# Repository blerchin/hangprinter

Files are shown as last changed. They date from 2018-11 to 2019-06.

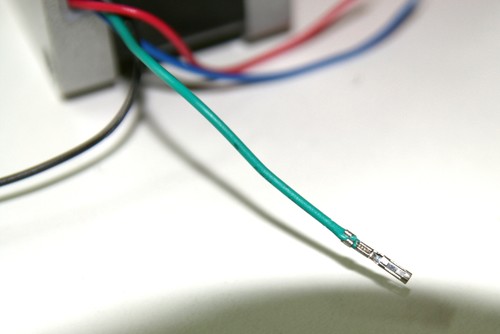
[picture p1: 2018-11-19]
doc/v3/media/Mechaduino_assembly/small_002.JPG

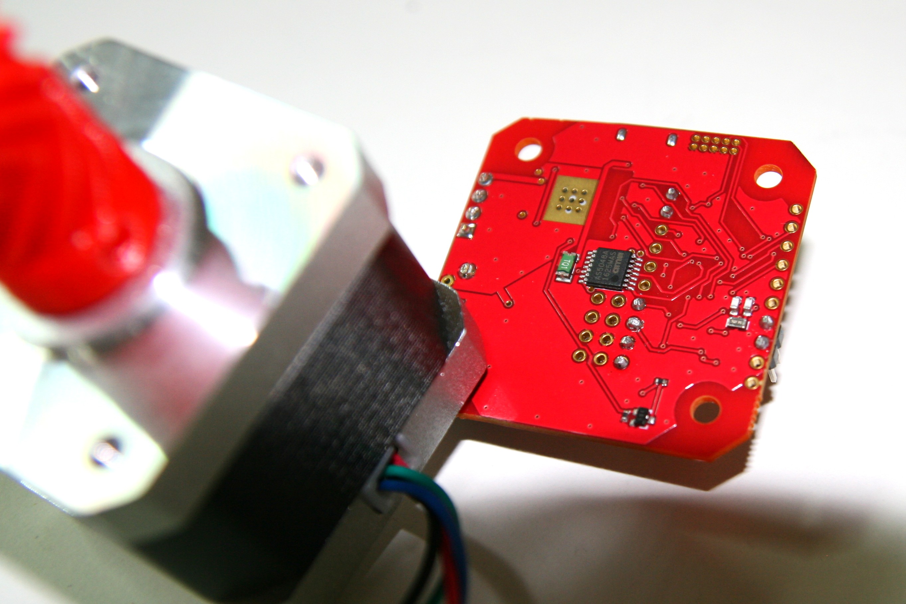
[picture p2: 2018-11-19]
doc/v3/media/Mechaduino_assembly/005.JPG

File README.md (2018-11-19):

Hangprinter Hangprinter logo
===========

This is the working branch of the Hangprinter repository.
Breaking changes may occur from time to time.
The Hangprinter repo does not yet have a stable branch.
This branch will become our (first!) stable branch when stock Marlin v2 is ready to be included as the default Hangprinter firmware.

This document and this repo are solely about technical aspects of Hangprinter version 3.
For more general information about the Hangprinter Project, refer to [hangprinter.org](https://hangprinter.org).

Bill of Materials
----------------
You can help fund future development of this project by using the affiliate links below when sourcing vitamins.
A Google Spreadsheet version for a Smart Stepper-driven setup, up to date as of Oct 10 2018, is found here: [Google docs](https://docs.google.com/spreadsheets/d/1lOPZoF1P2OSdJcijZRVrwAEVFh3LLAnf6-s6k-hlbZU/edit?usp=sharing)

Assembly Instructions
---------------------
The documentation hosted in this repo is published at [hangprinter.org/doc/v3](https://hangprinter.org/doc/v3).

Using Nema23?
----------------
Then you need different sized motor brackets, extruder holders and motor gears.
To compile those do
```
make nema23
```
This compiles the files and puts them in the `openscad_stl_nema23/` directory.
It also creates the `layout_nema23.dxf` file.
To make a 2d-printable pdf of the layout, do
```
make layout_nema23_a4.pdf
```

Using letter sized paper?
-------------------------
You can wedge that into the make-calls, like
```
make layout_letter.pdf
```
The following works if you're using nema23:
```
make layout_nema23_letter.pdf
```

The pdf creation command has been tested on a Ubuntu 14.04 system
with Cairosvg v1.0.4, sed v4.2.2, and Ghostscript v9.10.

Contributing Improvements
-------------------------
Your design improvements will help the rest of the community if you build your machine according to the files and instructions found in this repo.
The maintainers (me) are super grateful if you can structure your improvement into a pull request, and submit it to this repo.
See for example [this page](https://stackoverflow.com/questions/14680711/how-to-do-a-github-pull-request#14681796) for help with creating a pull request.

If your improvement can't be structured into a pull request, the second best option is to make an issue here on GitHub, or to contact us via the
[RepRap forum](https://reprap.org/forum/list.php?423).

Supporting This Project With Money
----------------------------------
Monthly donations can be set up via the [Bountysource Salt Campaign](https://salt.bountysource.com/teams/hangprinter).

Merchandise can be bought here: [Mechadise Sweden](http://spreadshirt.se/shops/hangprinter-merchandise).
And here: [Mechadise US](http://spreadshirt.com/shops/hangprinter-merchandise).

Bitcoin donations are accepted on: 1BwobkC5Tb7psWkzCugtcH21ufj6Lc9mgY
... or in QR format:<br />BTC Donations QR code

Credits
-------
See [contributors](https://gitlab.com/tobben/hangprinter/graphs/Openscad_version_3) for committer stats.
Note that almost all ideas implemented by the commits have come up in conversations among fellow Reprappers.
None mentioned, none forgotten, but you know who you are.
Thanks!

This repo also contains external code from many places. Some of them:
* [Greg Frost gears](http://www.thingiverse.com/thing:3575)
* [Marlin firmware](https://github.com/MarlinFirmware/Marlin)
* [scad-utils](https://github.com/openscad/scad-utils)

Currently donating $25 or more:
* [Add:north](https://addnorth.com/)
* [Aleph Objects](https://www.alephobjects.com/)
* [Alexander Osika](https://www.bountysource.com/people/49454-alexander-osika)
* [Bondtech](http://www.bondtech.se/)
* [Brooks Talley](https://www.bountysource.com/people/62525-brooks-talley)
* [David Lang](https://www.bountysource.com/people/50149-david-lang)
* [Delloman](https://www.bountysource.com/people/56602-delloman)
* [E3D](https://e3d-online.com)
* [Jeff Moe](https://www.bountysource.com/people/48391-jeff-moe)
* [John Downey](https://www.bountysource.com/people/60458-john-downey)
* [Peter Fischer](https://www.bountysource.com/people/63437-peter-fischer)

Lists sorted alphabetically.

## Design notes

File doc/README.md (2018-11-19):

# Hangprinter Documentation
This directory contains manuals written within the Hanpgrinter Project.
The files listed here are served at [hangprinter.org/doc](https://hangprinter.org/doc).

The intention is to document electronics, software, assembly, and calibration seperately and as independently as possible.
It should be possible to read them in any order and still have meaningful results.

On April 18, 2018, only the assembly manual is done. See v3/index.xml.

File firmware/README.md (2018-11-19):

## State of Hangprinter v3 firmware as of Sep 18, 2018

### Marlin
Hangprinter support was merged into Marlin's develpopment branch on Sep 9, 2018.
In this repo you'll find a copy of that development branch.
At the time of writing this, Hangprinter support has not been included in any Marlin releases yet, so we use the dev branch for now.

### Smart Stepper
Smart Stepper is a development of the Mechaduino board, capable of advanced closed loop stepper motor control.
The Smart Stepper boards provide Hangprinter with closed loop control (no skipped steps), torque mode, and encoder readings, which enable Hangprinter's semi-automatic calibration
procedure.

### No Mechaduino?
It is recommended to use the SmartStepper firmware even if you have Mechaduino hardware.
The Mechaduino firmware contained bugs that degraded Hangprinter accuracy slightly (see [this snippet](https://gitlab.com/snippets/1752083) for details).

To compile Smart Stepper Firmware for a Mechaduino board, you uncomment
```
#define MECHADUINO_HARDWARE
```
in `boards.h`, and comment out
```
#define NEMA17_SMART_STEPPER_3_21_2017
```
in the same file.

### Smart Stepper Wiring
The Smart Stepper LCD screens can not be used on a Hangprinter, since the SDA and SCL pins are needed for communicating with the host controller (RAMPS or whatever board
you've chosen for your HP3).

The Smart Stepper boards need to be configured with their own i2c addresses.
Marlin expects motor A to have i2c address 0x0a, motor b to have address 0x0b etc.
To check which i2c address your Smart Stepper has, issue
```
i2cid
```
via the serial port.
To set the address to for example `0x0b`, issue
```
i2cid 0x0b
```

It's recommended to check out the `ctrlmode` command as well.
There are two modes that can both work well with Hangprinter.

 * `controller Simple-Position-PID(2)`
 * `controller Current-Position-PID(3)`

The latter will give more silent and efficient operation on almost all motors, but requires you to do PID tuning through the `ppid` command.

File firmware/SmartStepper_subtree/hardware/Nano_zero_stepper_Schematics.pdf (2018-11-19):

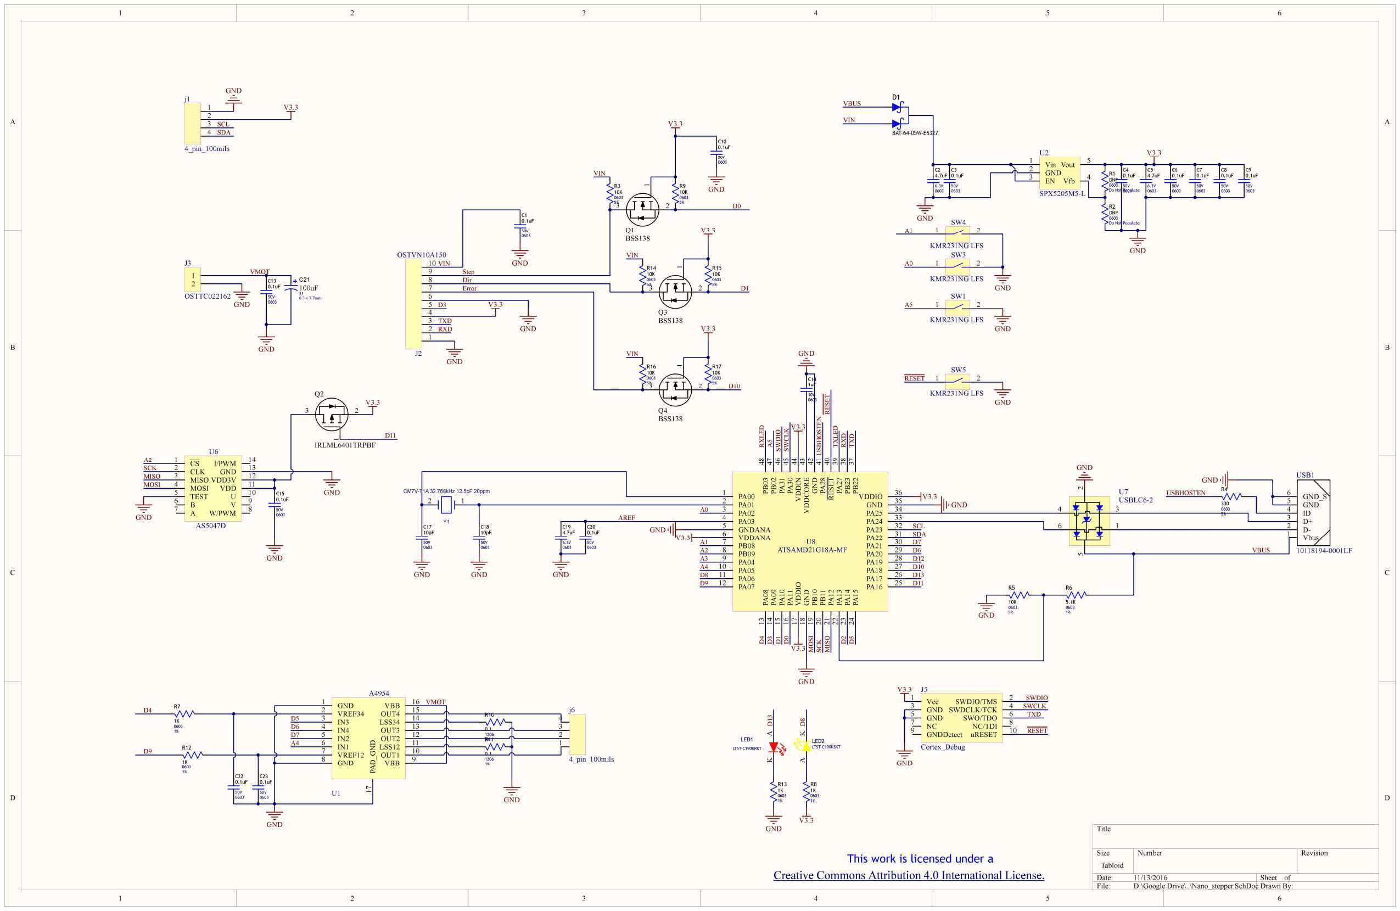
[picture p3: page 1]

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
Title

Size | Number | Revision
Tabloid
Date: | 11/13/2016 | Sheet of
File: | D:\Google Drive\..\Nano_stepper.SchDoc Drawn By:

CS 1
CLK 2
MISO 3
MOSI 4
TEST 5
B

6
A
7 | W/PWM | 8
| V | 9

U

10 VDD | 11 VDD3V | 12 GND | 13 I/PWM | 14

U6

AS5047D

PA00 1
PA01 2
PA02 3
PA03 4
GNDANA 5
VDDANA 6
PB08 7
PB09 8
PA04 9
PA05 10
PA06 11
PA07 12 | PA⁰⁸ 13 PA⁰⁹ 14 PA¹⁰ 15 PA¹¹ 16 VDDIO 17 GND 18 PB¹⁰ 19 PB¹¹ 20 PA¹² 21 PA¹³ 22 PA¹⁴ 23 PA¹⁵ 24
PA16 | 25 PA17 | 26 PA18 | 27 PA19 | 28 PA20 | 29 PA21 | 30 PA22 | 31 PA23 | 32 PA24 | 33 PA25 | 34 GND | 35 VDDIO PB²² | 36 ³⁷ PB²³ ³⁸ PA²⁷ ³⁹ RESET ⁴⁰ PA²⁸ ⁴¹ GND ⁴² VDDCORE ⁴³ VDDIN ⁴⁴ PA³⁰ ⁴⁵ PA³¹ ⁴⁶ PB⁰² ⁴⁷ PB⁰³ ⁴⁸

U8
ATSAMD21G18A-MF

2 1

Y1

CM7V-T1A 32.768kHz 12.5pF 20ppm

0603

50V

C18
10pF

0603

50V

C17
10pF
GND | GND | MOSI SCK MISO

VBUS

GND

GND

GND

GND

V3.3

V3.3

V3.3

V3.3

0603

10V

C14
1uF

GND

Vcc 1

| SWDIO/TMS | 2
GND 3
| SWDCLK/TCK | 4
GND 5
| SWO/TDO | 6
NC 7 | NC/TDI | 8
GNDDetect 9
| nRESET | 10

J5

# Cortex_Debug RESET

RESET SWDIO

SWDIO SWCLK

SWCLK

V3.3

GND A K LED2

LTST-C190KSKT

0603
1%

R13
1K
0603
1%

R8
1K

1 2

SW5

KMR231NG LFS
GND

RESET

A0
AREF

A1
A2
A3
A4
D8
D9 | D⁴ D³ D¹ D⁰ | D² D⁵

D11

D13

D10

D12

D6

D7

SDA

SCL RXD USBHOSTEN RXLED A⁵ | TXLED

A K
LED1

LTST-C190KRKT

# GNDD¹³

0603
5%

R4

330

USBHOSTEN

0603

50V

C20
0.1uF

0603

6.3V

C19
4.7uF

GND

# V3.3 D⁸

2 5

6

4

1

3

U7
USBLC6-2

GND

Vbus

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
GND_S

6

USB1

10118194-0001LF

TXD TXD

0603
5%

R5

10K
0603
1%

R6

5.1K
GND

A2

MOSI

MISO

SCK

GND

GND

Vin 1
GND 2
EN 3 | Vfb | 4
| Vout | 5

U2

SPX5205M5-L

GND

0603

50V

C4
0.1uF

0603

50V

C3
0.1uF

0603
Do Not Populate

R2
DNP

0603
Do Not Populate

R1
DNP

0603

50V

C6
0.1uF

0603

50V

C7
0.1uF

0603

50V

C8
0.1uF

0603

50V

C9
0.1uF

D1

BAT-64-05W-E6327

0603

6.3V

C5
4.7uF

VIN

VBUS

0603

6.3V

C2
4.7uF

V3.3

GND

0603

50V

C15
0.1uF

GND

GND

VMOT

GND

0603

50V

C13
0.1uF

VIN

D0

RXD | GND

GND

TXD

GND

D1

Step
Dir
Error

D3

### 6.3 x 7.7mm

100uF
35

C21

GND 1
VREF34 2
IN3 3
IN4 4
IN2 5
IN1 6
VREF12 7
GND 8 | VBB | 9
OUT1 | 10 LSS12 | 11 OUT2 | 12 OUT3 | 13 LSS34 | 14 OUT4 | 15 VBB | 16 PAD_GND
U1 | 17

A4954

D4

0603
1%

R7

1K

0603

50V

C22
0.1uF

0603

50V

C23
0.1uF

0603
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
1206
1%

R10

0.1

1206
1%

R11

0.1

VMOT

GND

1

2

3

4

j6

4_pin_100mils

D10

V3.3

D11

1 2

SW1

KMR231NG LFS
GND

1
2
3
4

j1

4_pin_100mils

A5

1 2

SW3

KMR231NG LFS
GND

A0

A4

1

3 2

Q2

IRLML6401TRPBF

1
2

J3

OSTTC022162

1 2

SW4

KMR231NG LFS

A1 ¹

3 2

Q1
BSS138

0603
5%

R3
10K

V3.3

0603
5%

R9
10K

VIN

0603

50V

C1
0.1uF | 1

3 2

Q3
BSS138

0603
5%

R14
10K

V3.3

0603
5%

R15
10K

# VIN 1

3 2

Q4
BSS138

0603
5%

R16
10K

V3.3

0603
5%

R17
10K

VIN

V3.3

0603

50V

C10
0.1uF

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
OSTVN10A150

SDA

SCL

V3.3

GND

## This work is licensed under a

Creative Commons Attribution 4.0 International License.

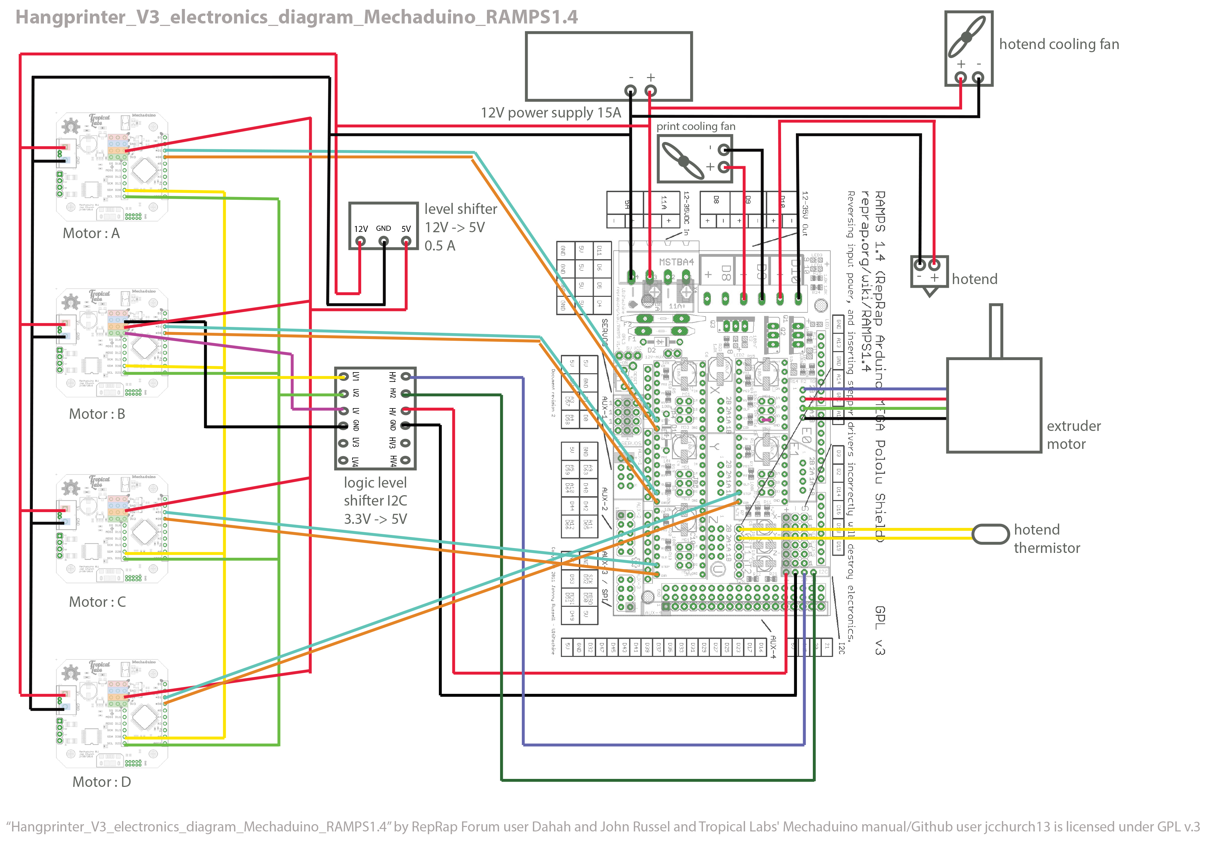
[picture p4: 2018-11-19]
doc/v3/media/Hangprinter_electronics_diagram_Mechaduino_RAMPS1.4_V2.3.jpg

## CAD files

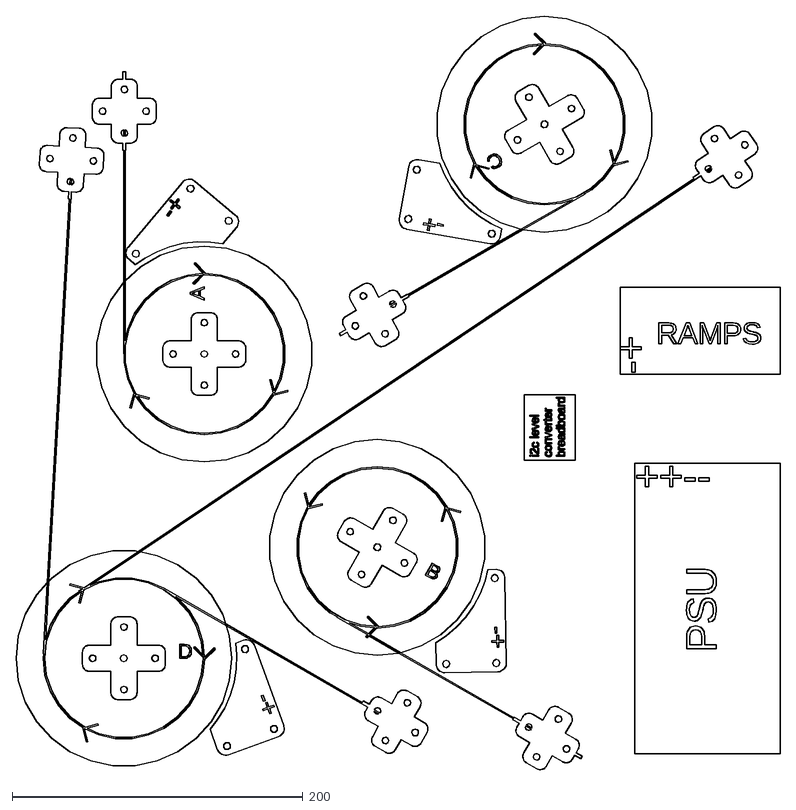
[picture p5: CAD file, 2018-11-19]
layout.dxf
525.5 x 518.1

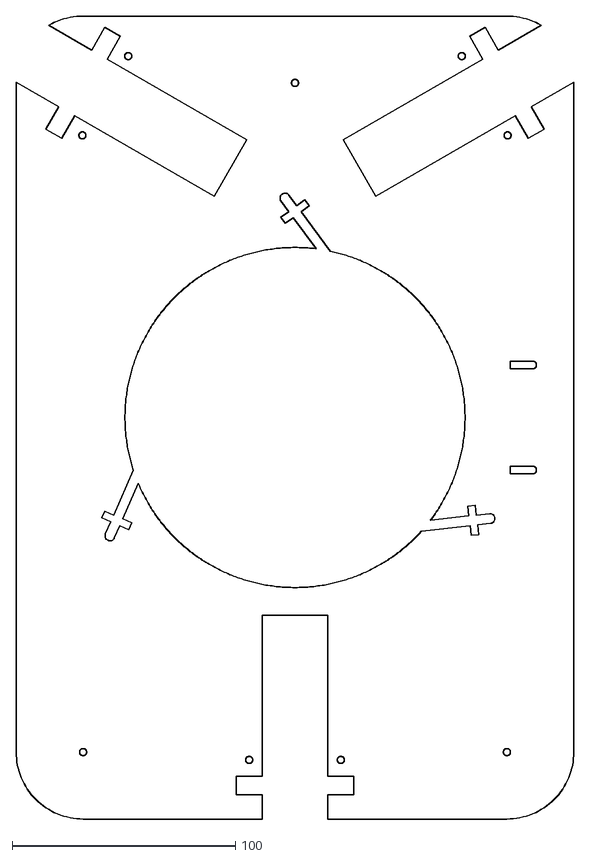
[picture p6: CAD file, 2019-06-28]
openscad_dxf/base_unit_4.dxf
250.0 x 360.0

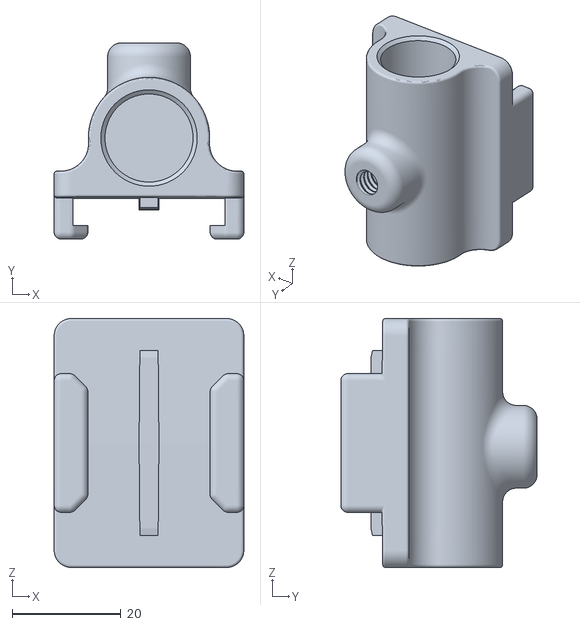
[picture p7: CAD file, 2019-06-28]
openscad_src/Light_Stand_GoPro_Mount.stl
34.9 x 36.2 x 45.8

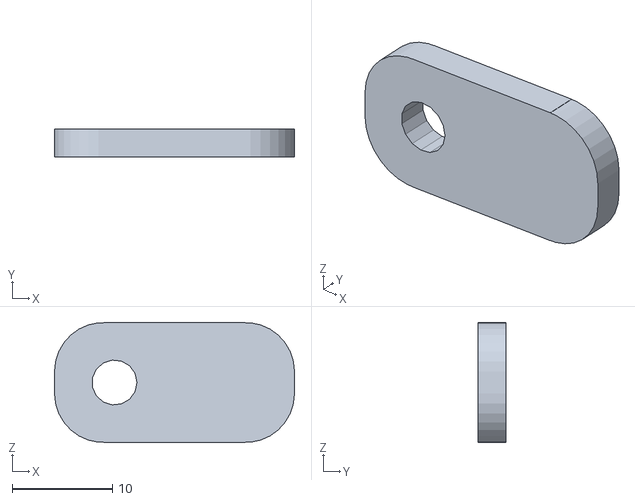
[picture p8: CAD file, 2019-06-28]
openscad_stl/axle_cover.stl
24.0 x 2.80 x 12.0

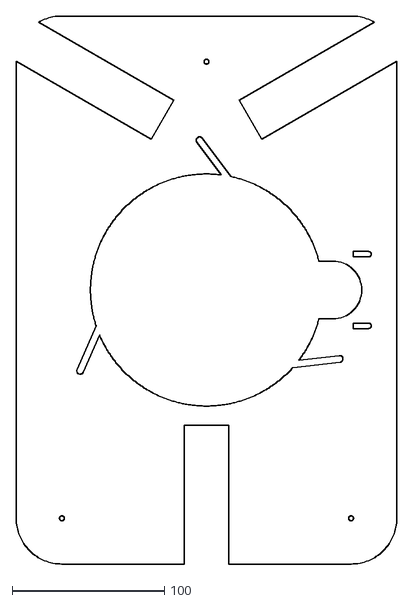
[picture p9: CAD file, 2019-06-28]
openscad_dxf/base_unit_2.dxf
250.0 x 360.0

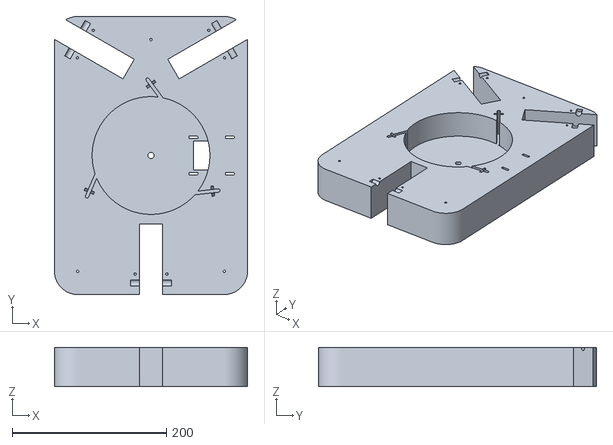
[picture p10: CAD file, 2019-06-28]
openscad_stl/base_unit.stl
250.0 x 360.0 x 50.8

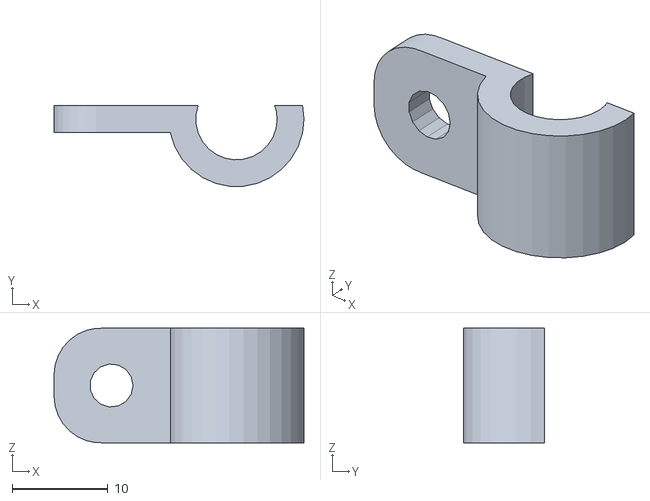
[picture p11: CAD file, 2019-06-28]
openscad_stl/axle_clamp.stl
26.1 x 8.41 x 12.0

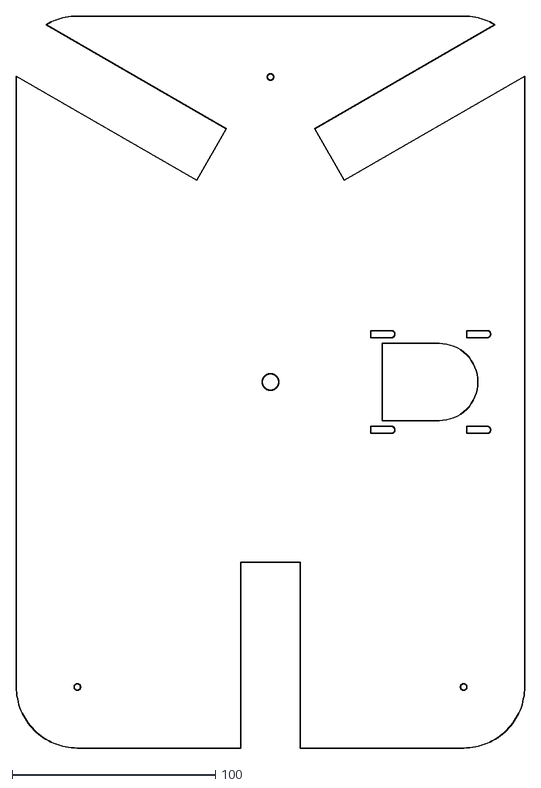
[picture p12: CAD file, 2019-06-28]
openscad_dxf/base_unit_1.dxf
250.0 x 360.0

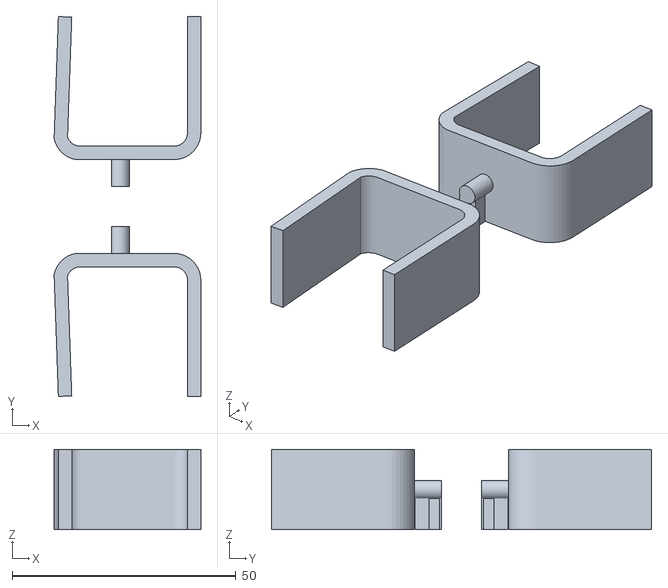
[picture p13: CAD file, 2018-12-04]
openscad_stl/lineroller_anchor_clip.stl
32.8 x 85.0 x 18.0

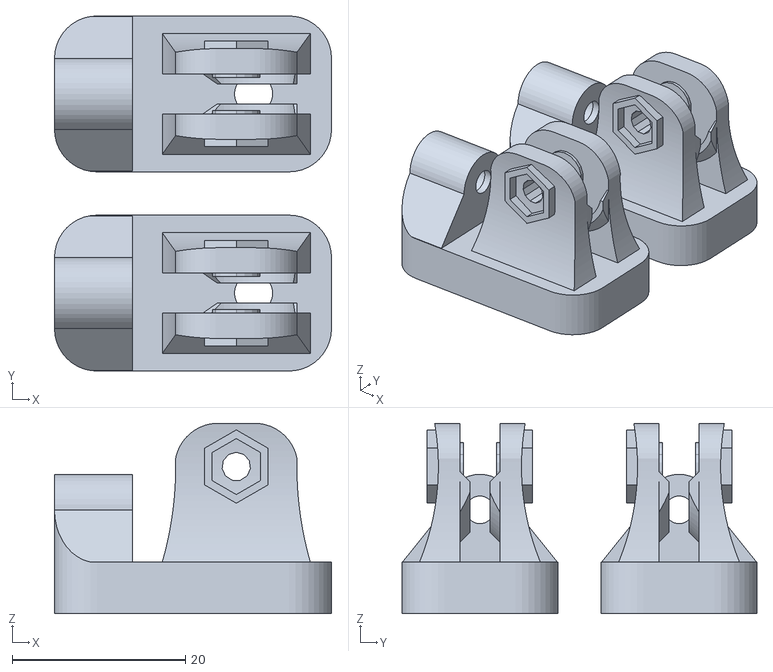
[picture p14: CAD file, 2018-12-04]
openscad_stl/lineroller_anchor_swivel.stl
32.0 x 41.0 x 22.0

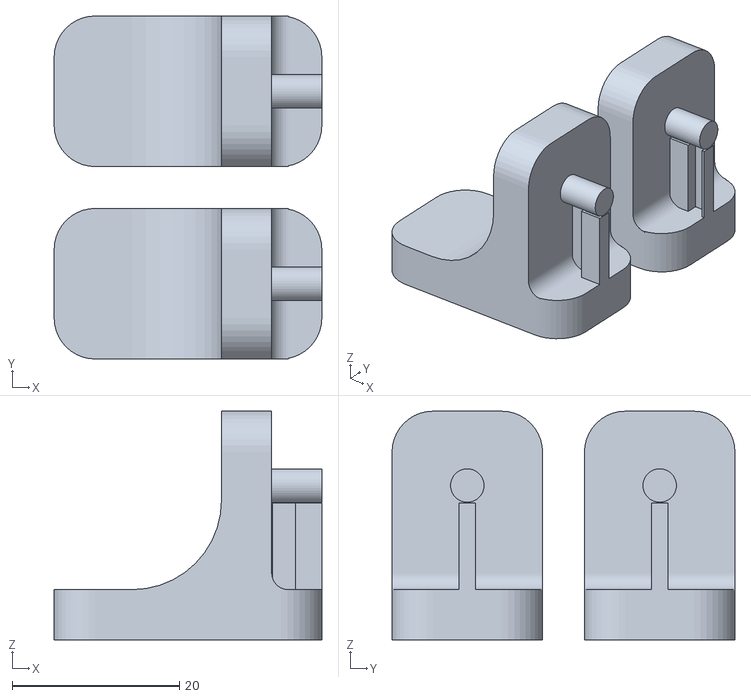
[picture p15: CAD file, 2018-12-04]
openscad_stl/lineroller_anchor_wall.stl
32.0 x 41.0 x 27.3

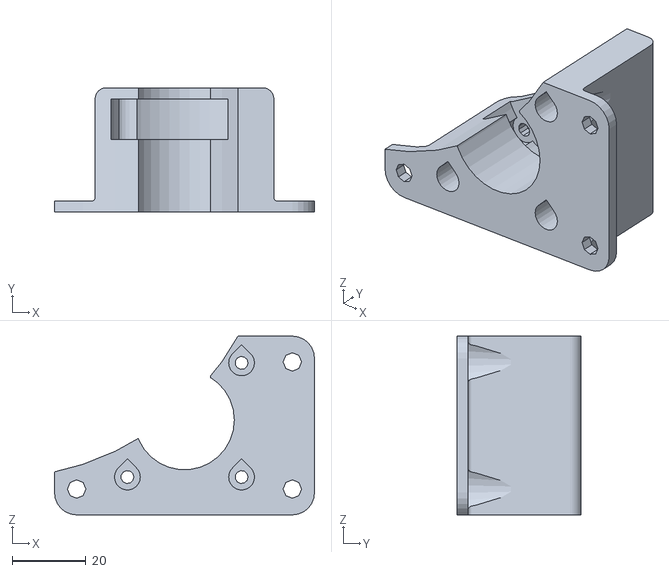
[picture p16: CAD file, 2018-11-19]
openscad_stl/motor_bracket.stl
70.4 x 33.7 x 48.4

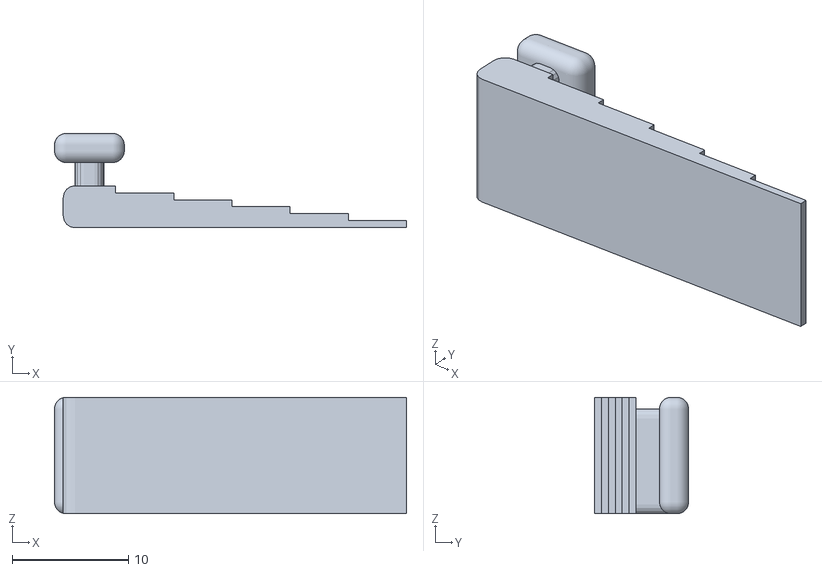
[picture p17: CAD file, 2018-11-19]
openscad_stl/beam_slider_D.stl
30.2 x 8.11 x 10.0

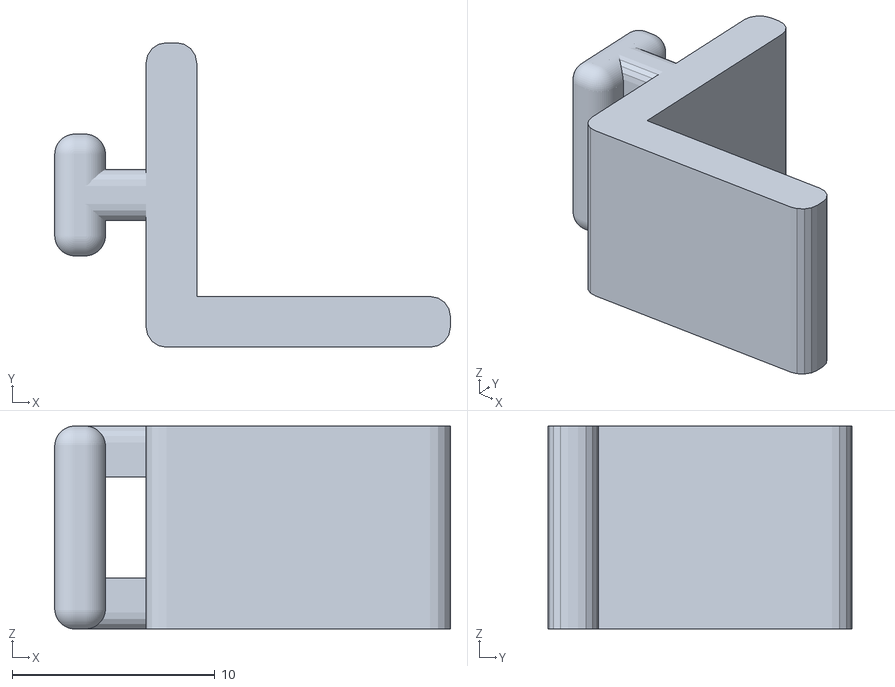
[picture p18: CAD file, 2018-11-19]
openscad_stl/beam_slider_ABC.stl
19.5 x 15.0 x 10.0

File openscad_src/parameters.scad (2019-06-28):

// Parameters shared between modules
Base_th = 2.8;
Beam_width = 15;
Wiggle = 0.25;
Fat_beam_width = Beam_width + Wiggle;
Beam_length = 400;
Wall_th = 2.5;
Min_beam_width = 12.5;
Max_beam_width = 17.5;
Zip_th = 2;
Zip_h = Zip_th + Max_beam_width - Min_beam_width;
Zip_w = 5.0;
Nema17_cube_width          = 42.43;
Nema17_screw_hole_width    = 43.74; // Opposite corner screws
Nema17_ring_diameter       = 22;
Nema17_cube_height         = 39.36;
Nema17_shaft_height        = 63.65;
Nema17_ring_height         = 2;
Nema17_shaft_radius        = 5/2;
Nema23_cube_width          = 56;
Nema23_screw_hole_width    = 66.61;
Nema23_ring_diameter       = 38;
Nema23_cube_height         = 56;
Nema23_shaft_radius        = 3.175;

b608_outer_dia = 22.2;
b608_width = 7.05;
Gap_between_sandwich_and_plate = 1.5 + Base_th; // 1.5 mm for wiggle
Motor_bracket_flerp_r = 6;
Motor_bracket_flerp = 14;
Motor_bracket_cw = Nema17_cube_width + 6;
Motor_bracket_att_ang = 50;
Mounting_screw_d = 4.5;
Mounting_screw_head_d = 14;
Spool_outer_wall_th = 4;

// Corner clamp parameters
Cc_l1 = (Fat_beam_width+2*Wall_th)*2*sqrt(3);
Cc_rad_b = 4;
Cc_action_point_from_mid = Cc_l1/sqrt(3)-2*Cc_rad_b-1.3;  // 1.3 chosen arbitrarily
Cc_plastic_length = sqrt(Cc_action_point_from_mid*Cc_action_point_from_mid
                       - (Cc_action_point_from_mid/2)*(Cc_action_point_from_mid/2));

// The distance between the two action points on the mover
Sidelength = Beam_length + 2*Cc_plastic_length;

/////// Layout parameters ////////////
Ext_sidelength = Sidelength+77;
Additional_added_plate_side_length = 10;
Yshift_top_plate = -25;

/////// Gear parameters ////////////
Circular_pitch = 262;
Motor_teeth = 10;
Gear_height = 21.4-3;
Motor_pitch                      = (Motor_teeth*Circular_pitch/360);
Motor_pitch_diametrial           = Motor_teeth/(2*Motor_pitch);
Motor_outer_radius               = Motor_pitch + 1/Motor_pitch_diametrial;
Spool_teeth = 100;
Spool_r = 55;
Spool_height = 8;
Spool_pitch                      = (Spool_teeth*Circular_pitch/360);
Spool_pitch_diametrial           = Spool_teeth/(2*Spool_pitch);
Spool_outer_radius               = Spool_pitch + 1/Spool_pitch_diametrial;
Torx_depth = 5;
Motor_bracket_depth = Gear_height+1+7+Nema17_ring_height+1+Gap_between_sandwich_and_plate;
Spool_core_flerp0 = 16+3;

/////// Lineroller parameters ////////////
b623_width  = 4;
b623_bore_r = 3/2;
b623_vgroove_big_r = 12/2;
b623_vgroove_small_r = 10/2;
Lineroller_wall_th = 2.3;
// The height that lineroller_ABC_winch will have if we include the bearing
Tower_h = Gap_between_sandwich_and_plate+Gear_height
         + Spool_height/2
         + b623_vgroove_small_r
         + b623_vgroove_big_r;
Bearing_wall = 1;
Depth_of_lineroller_tower = b623_width + 2*Wall_th; // 9
Depth_of_lineroller_base = Depth_of_lineroller_tower + 9; // 18
Ptfe_r = 2.1;
Lineroller_base_r = Depth_of_lineroller_base/2-1*(Ptfe_r+2);
Screw_h = 2;
Screw_head_h = 2;
Spool_center_bearing_wall_th = 5;

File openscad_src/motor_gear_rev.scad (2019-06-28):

include <parameters.scad>
use <util.scad>
use <gears.scad>
mirror();
motor_gear();
module motor_gear(){

  gear_height = Gear_height + 1; //Want extra millimeter to avoid first- and last layer problems.
  foot_height = 7;
  module half(){
    my_gear(Motor_teeth, gear_height/2+0.1, Circular_pitch, fac=1, slices = 2*gear_height, invert = true);
  }

  difference(){
    union(){
      translate([0,0,gear_height/2]){
        half();
        mirror([0,0,1])
          half();
      }
      translate([0,0,gear_height])
        cylinder(r=Motor_outer_radius, h=foot_height);
    }

    translate([0,0,-1])
      D_shaft(37);
    for(k=[0,120,240])
      rotate([0,0,k]){
        translate([0,Nema17_shaft_radius+0.5,gear_height])
          nutlock();
      }
    translate([0,0,gear_height+foot_height-1])
      cylinder(r1=2.5, r2=4, h=3);
    translate([0,0,gear_height+foot_height-7])
      cylinder(r=2.5, h=8);
    translate([-0.5,0,gear_height+foot_height-0.3])
      cube([1,Motor_outer_radius+1,1]);
    translate([-0.5,0,-0.7])
      cube([1,Motor_outer_radius+1,1]);

    // Cut bottom to avoid problems with elephant foot
    translate([0,0,-0.3])
    rotate_extrude(angle=360, convexity=5)
      translate([Motor_pitch-1.3,0])
      rotate([0,0,-70])
      square([4,5]);

  }
}
//  translate([0,0,-2-Nema17_cube_height])
//    Nema17();

echo("Motor gear outer radius",  Motor_outer_radius);
echo("Motor gear pitch", Motor_pitch);

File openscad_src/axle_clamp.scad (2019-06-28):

include <parameters.scad>
use <util.scad>

bit_width = 12;
axle_r=4.25;

module wing() {
  difference() {
   rotate([90,0,0])
      left_rounded_cube2([bit_width+2,bit_width,Base_th], Lineroller_base_r);
   screw();
  }


}

module screw() {
  translate([bit_width/2, 0, bit_width/2])
    rotate([90,0,0])
    translate([0,0,-1])
    cylinder(d=Mounting_screw_d, h=Base_th+2, $fs=1);
  translate([bit_width/2, 0, bit_width/2])
    rotate([90,0,0])
    translate([0,0,Base_th])
    cylinder(d2=Mounting_screw_head_d-4, d1=Mounting_screw_head_d, h=12, $fs=1);
}


difference(){
  union(){
    wing();
    translate([bit_width+axle_r+Base_th,-Base_th/2,0])
      cylinder(r=axle_r+Base_th, h=bit_width, $fs=1);
  }
  translate([0,0,-1])
    cube(bit_width+2*axle_r+2*Base_th);

  // axle...
    translate([bit_width+axle_r+Base_th,-Base_th/2,-1])
      cylinder(r=axle_r, h=bit_width+2, $fs=1);
}

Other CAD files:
logo.dxf
openscad_stl/extruder_holder.stl
openscad_stl/Mechaduino_standoff.stl
openscad_src/axle_cover.scad
gameoflife.blend
openscad_src/Mechaduino_standoff.scad
openscad_src/base_unit.scad
openscad_src/beam_slider_ABC.scad
openscad_src/beam_slider_D.scad
openscad_src/cable_clamp.scad
openscad_src/corner_clamp.scad
openscad_src/extruder_holder.scad
openscad_src/gear_util.scad
openscad_src/gears.scad
openscad_src/layout.scad
openscad_src/layout_slicer.scad
openscad_src/lineroller_ABC_winch.scad
openscad_src/lineroller_D.scad
openscad_src/lineroller_anchor.scad
openscad_src/lineroller_anchor_clip.scad
openscad_src/lineroller_anchor_swivel.scad
openscad_src/lineroller_anchor_template.scad
openscad_src/lineroller_anchor_tripod_bracket.scad
openscad_src/lineroller_anchor_wall.scad
openscad_src/lineroller_base.scad
openscad_src/motor_bracket.scad
openscad_src/motor_bracket_2d.scad
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

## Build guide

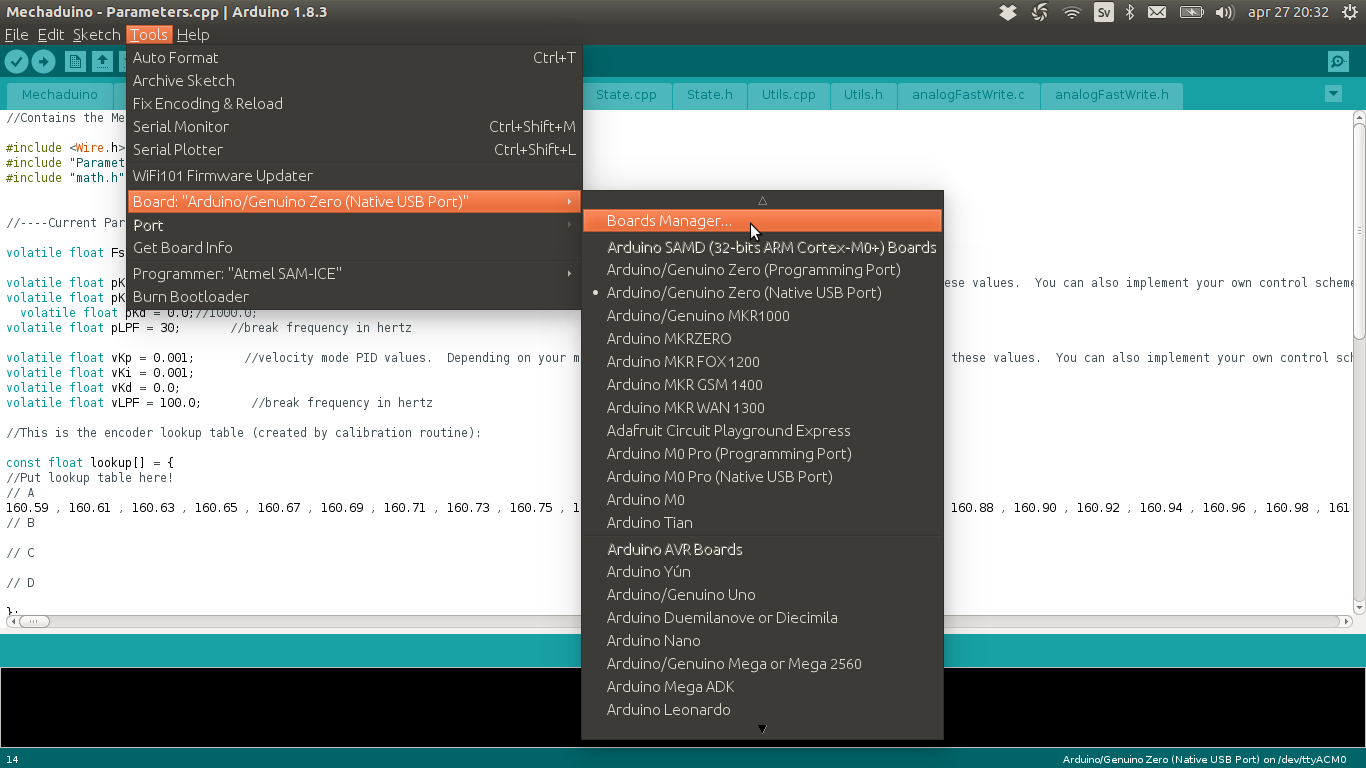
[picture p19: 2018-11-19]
doc/v3/media/Mechaduino_assembly/tools_menu2.png

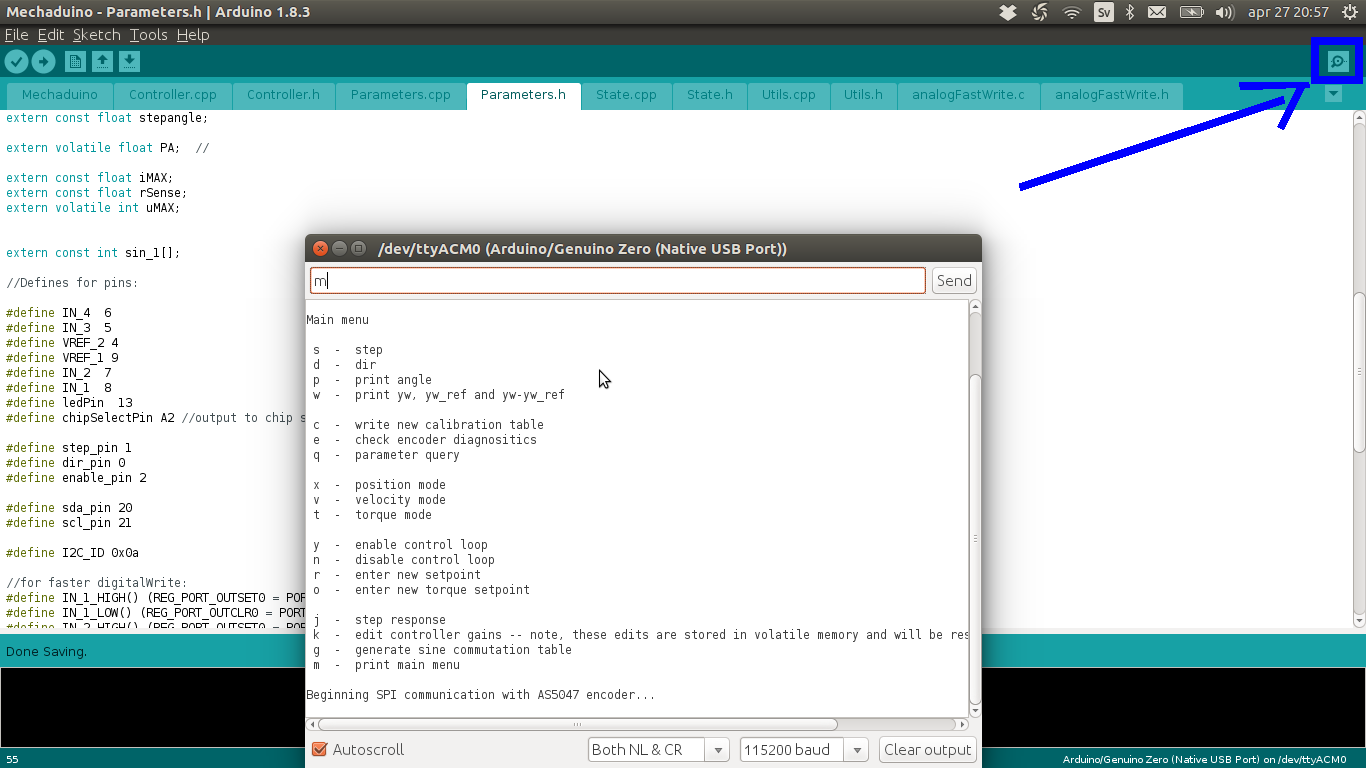
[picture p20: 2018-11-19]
doc/v3/media/Mechaduino_assembly/serial_monitor_usage_e.png

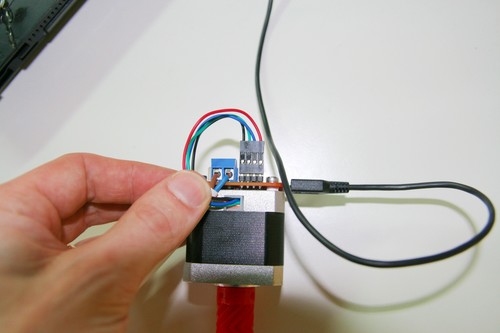
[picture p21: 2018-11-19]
doc/v3/media/Mechaduino_assembly/small_010.JPG

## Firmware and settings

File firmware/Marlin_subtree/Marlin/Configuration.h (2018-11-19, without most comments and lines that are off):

#define CONFIGURATION_H
#define CONFIGURATION_H_VERSION 010109
#define STRING_CONFIG_H_AUTHOR "(none, default config)" // Who made the changes.
#define SHOW_BOOTSCREEN
#define STRING_SPLASH_LINE1 SHORT_BUILD_VERSION // will be shown during bootup in line 1
#define STRING_SPLASH_LINE2 WEBSITE_URL         // will be shown during bootup in line 2
#define SERIAL_PORT 0
#define BAUDRATE 250000
  #define MOTHERBOARD BOARD_RAMPS_14_EFB
#define CUSTOM_MACHINE_NAME "Hangprinter"
#define EXTRUDERS 1
#define DEFAULT_NOMINAL_FILAMENT_DIA 3
#define POWER_SUPPLY 1
#define TEMP_SENSOR_0 5 // Setting gotten from wiki.e3d-online.net instructions for V6 hot end
#define TEMP_SENSOR_1 0
#define TEMP_SENSOR_2 0
#define TEMP_SENSOR_3 0
#define TEMP_SENSOR_4 0
#define TEMP_SENSOR_BED 0
#define TEMP_SENSOR_CHAMBER 0
#define DUMMY_THERMISTOR_998_VALUE 25
#define DUMMY_THERMISTOR_999_VALUE 100
#define MAX_REDUNDANT_TEMP_SENSOR_DIFF 10
#define TEMP_RESIDENCY_TIME 10  // (seconds)
#define TEMP_HYSTERESIS 3       // (degC) range of +/- temperatures considered "close" to the target one
#define TEMP_WINDOW     1       // (degC) Window around target to start the residency timer x degC early.
#define TEMP_BED_RESIDENCY_TIME 10  // (seconds)
#define TEMP_BED_HYSTERESIS 3       // (degC) range of +/- temperatures considered "close" to the target one
#define TEMP_BED_WINDOW     1       // (degC) Window around target to start the residency timer x degC early.
#define HEATER_0_MINTEMP 5
#define HEATER_1_MINTEMP 5
#define HEATER_2_MINTEMP 5
#define HEATER_3_MINTEMP 5
#define HEATER_4_MINTEMP 5
#define BED_MINTEMP 5
#define HEATER_0_MAXTEMP 275
#define HEATER_1_MAXTEMP 275
#define HEATER_2_MAXTEMP 275
#define HEATER_3_MAXTEMP 275
#define HEATER_4_MAXTEMP 275
#define BED_MAXTEMP 150
#define PIDTEMP
#define BANG_MAX 255     // Limits current to nozzle while in bang-bang mode; 255=full current
#define PID_MAX BANG_MAX // Limits current to nozzle while PID is active (see PID_FUNCTIONAL_RANGE below); 255=full current
#define PID_K1 0.95      // Smoothing factor within any PID loop
  #define PID_FUNCTIONAL_RANGE 10 // If the temperature difference between the target temperature and the actual temperature
  #define  DEFAULT_Kp 31.39
  #define  DEFAULT_Ki 2.80
  #define  DEFAULT_Kd 88.06
#define MAX_BED_POWER 255 // limits duty cycle to bed; 255=full current
#define PREVENT_COLD_EXTRUSION
#define EXTRUDE_MINTEMP 170
#define PREVENT_LENGTHY_EXTRUDE
#define EXTRUDE_MAXLENGTH 200
#define THERMAL_PROTECTION_HOTENDS // Enable thermal protection for all extruders
#define THERMAL_PROTECTION_BED     // Enable thermal protection for the heated bed
#define DEFAULT_E_AXIS_STEPS_PER_UNIT 410.0 // 410.0 set quite at random
#define HANGPRINTER
  #define KINEMATIC_SEGMENTS_PER_SECOND 40
  #define HANGPRINTER_PRINTABLE_RADIUS 1500.0
  #define ANCHOR_A_Y  -935
  #define ANCHOR_A_Z  -136
  #define ANCHOR_B_X   727
  #define ANCHOR_B_Y   458
  #define ANCHOR_B_Z  -136
  #define ANCHOR_C_X  -727
  #define ANCHOR_C_Y   458
  #define ANCHOR_C_Z  -136
  #define ANCHOR_D_Z  3565
  #define CONVENTIONAL_GEOMETRY
  #define LINE_BUILDUP_COMPENSATION_FEATURE
    #define MECHANICAL_ADVANTAGE { 1, 1, 1, 1 }
    #define ACTION_POINTS { 2, 2, 2, 3 }
    #define SPOOL_BUILDUP_FACTOR 0.0078
    #define MOUNTED_LINE { 7500.0, 7500.0, 7500.0, 5000.0 }
    #define SPOOL_RADII { 54.8, 54.8, 54.8, 54.8 }
    #define MOTOR_GEAR_TEETH { 10, 10, 10, 10 }
    #define SPOOL_GEAR_TEETH { 100, 100, 100, 100 }
#define UNREGISTERED_MOVE_SUPPORT
#define MECHADUINO_I2C_COMMANDS
#define ENDSTOPPULLUPS
#define X_MIN_ENDSTOP_INVERTING true  // set to true to invert the logic of the endstop.
#define Y_MIN_ENDSTOP_INVERTING true  // set to true to invert the logic of the endstop.
#define Z_MIN_ENDSTOP_INVERTING true  // set to true to invert the logic of the endstop.
#define X_MAX_ENDSTOP_INVERTING true  // set to true to invert the logic of the endstop.
#define Y_MAX_ENDSTOP_INVERTING true  // set to true to invert the logic of the endstop.
#define Z_MAX_ENDSTOP_INVERTING true  // set to true to invert the logic of the endstop.
#define Z_MIN_PROBE_ENDSTOP_INVERTING true  // set to true to invert the logic of the probe.
#define DEFAULT_AXIS_STEPS_PER_UNIT   { 92.599, 92.599, 92.599, 92.599, DEFAULT_E_AXIS_STEPS_PER_UNIT }
#define DEFAULT_MAX_FEEDRATE          { 500, 500, 500, 300, 25 }
#define DEFAULT_MAX_ACCELERATION      { 1000, 1000, 1000, 1000, 10000 }
#define DEFAULT_ACCELERATION          600    // X, Y, Z and E acceleration for printing moves
#define DEFAULT_RETRACT_ACCELERATION  3000    // E acceleration for retracts
#define DEFAULT_TRAVEL_ACCELERATION   900    // X, Y, Z acceleration for travel (non printing) moves
#define DEFAULT_AJERK                 13.0
#define DEFAULT_BJERK                 13.0
#define DEFAULT_CJERK                 13.0
#define DEFAULT_DJERK                 13.0
#define DEFAULT_EJERK                  5.0
#define Z_MIN_PROBE_USES_Z_MIN_ENDSTOP_PIN
#define X_PROBE_OFFSET_FROM_EXTRUDER 0     // X offset: -left  +right  [of the nozzle]
#define Y_PROBE_OFFSET_FROM_EXTRUDER -10   // Y offset: -front +behind [the nozzle]
#define Z_PROBE_OFFSET_FROM_EXTRUDER -3.5  // Z offset: -below +above  [the nozzle]
#define MIN_PROBE_EDGE 10
#define XY_PROBE_SPEED 4000
#define Z_PROBE_SPEED_FAST DUMMY_HOMING_FEEDRATE
#define Z_PROBE_SPEED_SLOW (Z_PROBE_SPEED_FAST / 2)
#define Z_CLEARANCE_DEPLOY_PROBE   15 // Z Clearance for Deploy/Stow
#define Z_CLEARANCE_BETWEEN_PROBES  5 // Z Clearance between probe points
#define Z_CLEARANCE_MULTI_PROBE     5 // Z Clearance between multiple probes
#define Z_PROBE_LOW_POINT          -2 // Farthest distance below the trigger-point to go before stopping
#define Z_PROBE_OFFSET_RANGE_MIN -20
#define Z_PROBE_OFFSET_RANGE_MAX 20
#define X_ENABLE_ON 0
#define Y_ENABLE_ON 0
#define Z_ENABLE_ON 0
#define E_ENABLE_ON 0 // For all extruders
#define DISABLE_X false
#define DISABLE_Y false
#define DISABLE_Z false
#define DISABLE_E false // For all extruders
#define DISABLE_INACTIVE_EXTRUDER false // Keep only the active extruder enabled.
#define INVERT_A_DIR false
#define INVERT_B_DIR true
#define INVERT_C_DIR false
#define INVERT_D_DIR false
#define INVERT_X_DIR INVERT_A_DIR
#define INVERT_Y_DIR INVERT_B_DIR
#define INVERT_Z_DIR INVERT_C_DIR
#if EXTRUDERS == 1
  #define INVERT_E1_DIR INVERT_D_DIR
#elif EXTRUDERS == 2
  #define INVERT_E2_DIR INVERT_D_DIR
#elif EXTRUDERS == 3
  #define INVERT_E3_DIR INVERT_D_DIR
#elif EXTRUDERS == 4
  #define INVERT_E4_DIR INVERT_D_DIR
#endif
#define INVERT_E0_DIR false
#if EXTRUDERS != 1
  #define INVERT_E1_DIR false
#endif
#if EXTRUDERS != 2
  #define INVERT_E2_DIR false
#endif
#if EXTRUDERS != 3
  #define INVERT_E3_DIR false
#endif
#if EXTRUDERS != 4
  #define INVERT_E4_DIR false
#endif
#define X_HOME_DIR 1  // Doesn't make sense for Hangprinter since it doesn't move while homing
#define Y_HOME_DIR 1
#define Z_HOME_DIR 1
#define X_BED_SIZE ((HANGPRINTER_PRINTABLE_RADIUS) * 2)
#define Y_BED_SIZE ((HANGPRINTER_PRINTABLE_RADIUS) * 2)
#define X_MIN_POS -(HANGPRINTER_PRINTABLE_RADIUS)
#define Y_MIN_POS -(HANGPRINTER_PRINTABLE_RADIUS)
#define Z_MIN_POS 0
#define X_MAX_POS HANGPRINTER_PRINTABLE_RADIUS
#define Y_MAX_POS HANGPRINTER_PRINTABLE_RADIUS
#define Z_MAX_POS (ANCHOR_D_Z - 300.0)
#define BED_CENTER_AT_0_0
#define DUMMY_HOMING_FEEDRATE  (200*60)
#define HOMING_FEEDRATE_XY (50*60)
#define HOMING_FEEDRATE_Z  (4*60)
#define EEPROM_SETTINGS // Enable for M500 and M501 commands
#define EEPROM_CHITCHAT   // Give feedback on EEPROM commands. Disable to save PROGMEM.
#define HOST_KEEPALIVE_FEATURE        // Disable this if your host doesn't like keepalive messages
#define DEFAULT_KEEPALIVE_INTERVAL 2  // Number of seconds between "busy" messages. Set with M113.
#define BUSY_WHILE_HEATING            // Some hosts require "busy" messages even during heating
#define PREHEAT_1_TEMP_HOTEND 180
#define PREHEAT_1_TEMP_BED     70
#define PREHEAT_1_FAN_SPEED   255 // Value from 0 to 255
#define PREHEAT_2_TEMP_HOTEND 240
#define PREHEAT_2_TEMP_BED    100
#define PREHEAT_2_FAN_SPEED   255 // Value from 0 to 255
#define PRINTJOB_TIMER_AUTOSTART
#define LCD_LANGUAGE en
#define DISPLAY_CHARSET_HD44780 JAPANESE
#define SOFT_PWM_SCALE 0
#define SERVO_DELAY { 300 }

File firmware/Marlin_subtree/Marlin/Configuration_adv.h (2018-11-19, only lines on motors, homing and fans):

#define E0_AUTO_FAN_PIN -1
#define E1_AUTO_FAN_PIN -1
#define E2_AUTO_FAN_PIN -1
#define E3_AUTO_FAN_PIN -1
#define E4_AUTO_FAN_PIN -1
#define CHAMBER_AUTO_FAN_PIN -1
#define X_HOME_BUMP_MM 5
#define Y_HOME_BUMP_MM 5
#define Z_HOME_BUMP_MM 5
#define HOMING_BUMP_DIVISOR { 10, 10, 10 }  // Re-Bump Speed Divisor (Divides the Homing Feedrate)
#define MICROSTEP_MODES { 16, 16, 16, 16, 16 } // [1,2,4,8,16]
#define DIGIPOT_I2C_MOTOR_CURRENTS { 1.0, 1.0, 1.0, 1.0, 1.0, 1.0, 1.0, 1.0 }  //  AZTEEG_X3_PRO

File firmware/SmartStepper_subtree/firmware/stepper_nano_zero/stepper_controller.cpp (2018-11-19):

/**********************************************************************
 *      Author: tstern
 *
 *	Misfit Tech invests time and resources providing this open source code,
 *	please support Misfit Tech and open-source hardware by purchasing
 *	products from Misfit Tech, www.misifittech.net!
 *
 *	Written by Trampas Stern  for Misfit Tech.
 *	BSD license, check license.txt for more information
 *	All text above, must be included in any redistribution
 *********************************************************************/
#include "stepper_controller.h"

#include "nonvolatile.h" //for programmable parameters
#include <Wire.h>
#include <inttypes.h>
#include "steppin.h"

#pragma GCC push_options
#pragma GCC optimize ("-Ofast")

#define WAIT_TC16_REGS_SYNC(x) while(x->COUNT16.STATUS.bit.SYNCBUSY);

volatile bool TC5_ISR_Enabled=false;

void setupTCInterrupts() {



	// Enable GCLK for TC4 and TC5 (timer counter input clock)
	GCLK->CLKCTRL.reg = (uint16_t) (GCLK_CLKCTRL_CLKEN | GCLK_CLKCTRL_GEN_GCLK0 | GCLK_CLKCTRL_ID(GCM_TC4_TC5));
	while (GCLK->STATUS.bit.SYNCBUSY);

	TC5->COUNT16.CTRLA.reg &= ~TC_CTRLA_ENABLE;   // Disable TCx
	WAIT_TC16_REGS_SYNC(TC5)                      // wait for sync

	TC5->COUNT16.CTRLA.reg |= TC_CTRLA_MODE_COUNT16;   // Set Timer counter Mode to 16 bits
	WAIT_TC16_REGS_SYNC(TC5)

	TC5->COUNT16.CTRLA.reg |= TC_CTRLA_WAVEGEN_MFRQ; // Set TC as normal Normal Frq
	WAIT_TC16_REGS_SYNC(TC5)

	TC5->COUNT16.CTRLA.reg |= TC_CTRLA_PRESCALER_DIV1;   // Set perscaler
	WAIT_TC16_REGS_SYNC(TC5)


	TC5->COUNT16.CC[0].reg = F_CPU/NZS_CONTROL_LOOP_HZ;
	WAIT_TC16_REGS_SYNC(TC5)


	TC5->COUNT16.INTENSET.reg = 0;              // disable all interrupts
	TC5->COUNT16.INTENSET.bit.OVF = 1;          // enable overfollow
	//  TC5->COUNT16.INTENSET.bit.MC0 = 1;         // enable compare match to CC0


	NVIC_SetPriority(TC5_IRQn, 2);


	// Enable InterruptVector
	NVIC_EnableIRQ(TC5_IRQn);


	// Enable TC
	TC5->COUNT16.CTRLA.reg |= TC_CTRLA_ENABLE;
	WAIT_TC16_REGS_SYNC(TC5)

}

static void enableTCInterrupts() {

	TC5_ISR_Enabled=true;
	NVIC_EnableIRQ(TC5_IRQn);
	TC5->COUNT16.INTENSET.bit.OVF = 1;
	//  TC5->COUNT16.CTRLA.reg |= TC_CTRLA_ENABLE;    //Enable TC5
	//  WAIT_TC16_REGS_SYNC(TC5)                      //wait for sync
}

static void disableTCInterrupts() {

	TC5_ISR_Enabled=false;
	//NVIC_DisableIRQ(TC5_IRQn);
	TC5->COUNT16.INTENCLR.bit.OVF = 1;
}

static bool enterCriticalSection()
{
	bool state=TC5_ISR_Enabled;
	disableTCInterrupts();
	return state;
}

static void exitCriticalSection(bool prevState)
{
	if (prevState)
	{
		enableTCInterrupts();
	} //else do nothing
}


void StepperCtrl::updateParamsFromNVM(void)
{
	bool state=enterCriticalSection();

	pPID.Kd=NVM->pPID.Kd*CTRL_PID_SCALING;
	pPID.Ki=NVM->pPID.Ki*CTRL_PID_SCALING;
	pPID.Kp=NVM->pPID.Kp*CTRL_PID_SCALING;

	vPID.Kd=NVM->vPID.Kd*CTRL_PID_SCALING;
	vPID.Ki=NVM->vPID.Ki*CTRL_PID_SCALING;
	vPID.Kp=NVM->vPID.Kp*CTRL_PID_SCALING;

	sPID.Kd=NVM->sPID.Kd*CTRL_PID_SCALING;
	sPID.Ki=NVM->sPID.Ki*CTRL_PID_SCALING;
	sPID.Kp=NVM->sPID.Kp*CTRL_PID_SCALING;

	if (NVM->SystemParams.parametersVaild)
	{
		memcpy((void *)&systemParams, (void *)&NVM->SystemParams, sizeof(systemParams));
		LOG("Home pin %d",systemParams.homePin);

	}else
	{
		ERROR("This should never happen but just in case");
		systemParams.microsteps=16;
		#if defined(CTRL_POS_PID_AS_DEFAULT)
			systemParams.controllerMode=CTRL_POS_PID;
		#else
			systemParams.controllerMode=CTRL_SIMPLE;
		#endif
		systemParams.dirPinRotation=CW_ROTATION; //default to clockwise rotation when dir is high
		systemParams.errorLimit=(int32_t)ANGLE_FROM_DEGREES(1.8);
		systemParams.errorPinMode=ERROR_PIN_MODE_ENABLE;  //default to enable pin
		systemParams.errorLogic=false;
		systemParams.homeAngleDelay=ANGLE_FROM_DEGREES(10);
		systemParams.homePin=-1; //no homing pin configured
	}

	//default the error pin to input, if it is an error pin the
	// handler for this will change the pin to be an output.
	// for bidirection error it has to handle input/output it's self as well.
	// This is not the cleanest way to handle this...
	// TODO implement this cleaner?
	pinMode(PIN_ERROR, INPUT_PULLUP); //we have input pin

	if (NVM->motorParams.parametersVaild)
	{
		memcpy((void *)&motorParams, (void *)&NVM->motorParams, sizeof(motorParams));
	} else
	{
		//MotorParams_t Params;
		motorParams.fullStepsPerRotation=200;
		motorParams.currentHoldMa=500;
		motorParams.currentMa=800;
		motorParams.homeHoldMa=200;
		motorParams.homeMa=800;
		motorParams.motorWiring=true;
		//memcpy((void *)&Params, (void *)&motorParams, sizeof(motorParams));
		//nvmWriteMotorParms(Params);
	}

	stepperDriver.setRotationDirection(motorParams.motorWiring);

	exitCriticalSection(state);
}


void  StepperCtrl::motorReset(void)
{
	//when we reset the motor we want to also sync the motor
	// phase.  Therefore we move forward a few full steps then back
	// to sync motor phasing, leaving the motor at "phase 0"
	bool state=enterCriticalSection();

	//	stepperDriver.move(0,motorParams.currentMa);
	//	delay(100);
	//	stepperDriver.move(A4954_NUM_MICROSTEPS,motorParams.currentMa);
	//	delay(100);
	//	stepperDriver.move(A4954_NUM_MICROSTEPS*2,motorParams.currentMa);
	//	delay(100);
	//	stepperDriver.move(A4954_NUM_MICROSTEPS*3,motorParams.currentMa);
	//	delay(100);
	//	stepperDriver.move(A4954_NUM_MICROSTEPS*2,motorParams.currentMa);
	//	delay(100);
	//	stepperDriver.move(A4954_NUM_MICROSTEPS,motorParams.currentMa);
	//	delay(100);
	stepperDriver.move(0,motorParams.currentMa);
	delay(1000);

	setLocationFromEncoder(); //measure new starting point
	exitCriticalSection(state);
}
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

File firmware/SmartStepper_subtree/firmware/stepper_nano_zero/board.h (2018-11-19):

/**********************************************************************
 *      Author: tstern
 *
 *	Misfit Tech invests time and resources providing this open source code,
 *	please support Misfit Tech and open-source hardware by purchasing
 *	products from Misfit Tech, www.misifittech.net!
 *
 *	Written by Trampas Stern  for Misfit Tech.
 *	BSD license, check license.txt for more information
 *	All text above, must be included in any redistribution
 *********************************************************************/
#ifndef __BOARD_H__
#define __BOARD_H__

#include <Arduino.h>

//uncomment this if you are using the Mechaduino hardware
//#define MECHADUINO_HARDWARE

//uncomment this if you will be using Hangprinter's TWI/i2c interface
#define HP_I2C

//uncomment the follow lines if using the NEMA 23 10A hardware
//#define NEMA_23_10A_HW

//uncomment the following if the board uses the A5995 driver (NEMA 23 3.2A boards)
//#define A5995_DRIVER

//The March 21 2017 NEMA 17 Smart Stepper has changed some pin outs
// A1 was changed to read motor voltage, hence SW4 is now using D4
// comment out this next line if using the older hardware
#define NEMA17_SMART_STEPPER_3_21_2017


#ifdef A5995_DRIVER
#ifdef NEMA17_SMART_STEPPER_3_21_2017
#error "Only NEMA17_SMART_STEPPER_3_21_2017 or A5595_DRIVER may be defined"
#endif
#endif

#define NZS_FAST_CAL // define this to use 32k of flash for fast calibration table
#define NZS_FAST_SINE //uses 2048 extra bytes to implement faster sine tables


#define NZS_AS5047_PIPELINE //does a pipeline read of encoder, which is slightly faster

#define NZS_CONTROL_LOOP_HZ (6000) //update rate of control loop


#define NZS_LCD_ABSOULTE_ANGLE  //define this to show angle from zero in positive and negative direction
// for example 2 rotations from start will be angle of 720 degrees

//#define ENABLE_PHASE_PREDICTION //this enables prediction of phase at high velocity to increase motor speed
//as of FW0.11 it is considered development only

#define VERSION "FW: 0.37" //this is what prints on LCD during splash screen

//Define this to allow command out serial port, else hardware serial is debug log
//#define CMD_SERIAL_PORT

#define SERIAL_BAUD (115200) //baud rate for the serial ports

//This section is for using the step and dir pins as serial port
// when the enable pin is inactive.
#define USE_STEP_DIR_SERIAL
#define STEP_DIR_BAUD (19200) //this is the baud rate we will use

// These are used as an attempt to use TC4 to count steps
//  currently this is not working.
//#define USE_NEW_STEP //define this to use new step method
#define USE_TC_STEP //use timer counter for step pin

#ifndef F_CPU
#define F_CPU (48000000UL)
#endif

/* TODO are flaged with TODO
 *   TODO - add detection of magnet to make sure PCB is on motor
 */
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

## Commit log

2018-11-19 fork with changes for dma fablab
    [Configuration.h, Configuration_adv.h, Mechaduino_standoff.scad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]
2018-12-03 add wall anchor model
    [lineroller_anchor_wall.scad, lineroller_anchor_wall.stl]
2018-12-03 fix watertight issues and add screw holes
    [lineroller_anchor_wall.scad, lineroller_anchor_wall.stl]
2018-12-03 wall anchor support improvements
    [lineroller_anchor_wall.scad, lineroller_anchor_wall.stl]
2018-12-04 add clip and separate roller/fitment files
    [lineroller_anchor_clip.scad, lineroller_anchor_clip.stl, lineroller_anchor_swivel.scad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]
2018-12-24 add base unit experiments
    [base_unit.scad, base_unit_d_internal.scad, base_unit_sidemount.scad]
2018-12-24 add stls of base_unit
    [base_unit.stl, base_unit_d_internal.stl, base_unit_sidemount.stl]
2019-01-11 fix D-roller position and add axle as part of mock_spool
    [base_unit_d_internal.scad]
2019-01-12 add internal motors
    [base_unit_d_internal.scad]
2019-01-12 add access for motor and lineroller screws
    [base_unit_d_internal.scad]
2019-01-12 add D motor mount
    [base_unit_d_internal.scad, base_unit_d_internal.stl]
2019-01-18 v1 slices
    [base_unit_d_internal.scad, base_unit_d_internal0.dxf, base_unit_d_internal1.dxf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]
2019-03-19 tweaks for working unit
    [base_unit_d_internal.scad]
2019-06-28 clean up and commit all changes c. solo show
    [Light_Stand_GoPro_Mount.stl, axle_clamp.scad, axle_clamp.stl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]

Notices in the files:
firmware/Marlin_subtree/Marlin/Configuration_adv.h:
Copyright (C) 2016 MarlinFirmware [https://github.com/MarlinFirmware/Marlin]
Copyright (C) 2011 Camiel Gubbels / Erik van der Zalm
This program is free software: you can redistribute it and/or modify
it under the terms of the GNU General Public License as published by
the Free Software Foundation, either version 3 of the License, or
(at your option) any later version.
